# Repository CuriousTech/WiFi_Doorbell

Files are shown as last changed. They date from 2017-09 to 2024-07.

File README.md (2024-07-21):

# WiFi Doorbell Chime

This is a very small doorbell chime based closely on the older version for displaying weather and sending notifications, but eliminates the old mechanical chime. The additional parts are a MOSFET to produce PWM sound, a resistor to eliminate the chime coil and allow parasitic power to supply a smart doorbell or button light, and a WS2812B LED ring, but is still compatible with the old project. The resistor should be about 100 ohms to allow power to the smart doorbell, but I don't know the current rating for them all. A 5W should be sufficient. It's connected to the transformer while the button is pressed, so it needs to handle the current for that time.  
  
Simple operation for detection: The way this circuit operates is when the button is pressed, the optocoupler is disalbled (parrallel to the light in the button), causing the GPIO port (with internal pullup) to go low. The optocoupler vf is 1.2V up to 50mA, but works at 10mA or maybe less. The limiting resistor value will be different for 12V or 24V, so use the proper value. 1K-1K2 is fine for 12V, 2K2-2K4 should be good for 24V, and likely works for 12V as well.  
  
The 3D printed parts have 2 options: A plastic grill or a retainer ring to wrap cloth around and glue. I prefer the latter. The diffuser ring is printed in clear.  
  
esp07doorbell2  
esp07doorbellparts  
esp07doorbellcolor  
  
The OLED version back with 433MHz receiver behind OLED display (cut a bit of plastic) for Reolink video doorbell RF433 output, which works the same as a standard keyfob.  
doorbellreolink  

Previous version below.  

This is an ESP07 based doorbell notifier.  

The 3 terminals connect to the existing 12~24VAC (up to 40V) transformer used to power the bell solenoids and light the neon bulb in the button.  

Btn-DB connects to the wire coming from the button and connects to the bell.<br/>
Btn-TF is the one with a wire cap between the transformer and button.  <br/>
TF-DB is the one coming from the transformer and connects to the bell.<br/>

This uses PushBullet for notifications, which can be enabled from the control page as well as a short list of ring times and last PIR motion trigger time.  It also uses ESPAsyncWebServer for pages, events, WebSockets, Weather Underground, PushBullet and the AP config.  

Wunderground is used for forcast and weather alerts.  If the OLED is truned off, it will only turn on for flashing a bell icon with time, when the PIR motion sensor is triggered (doorbell times will clear after it times out), or a weather alert is active. If the OLED is on, it will show a current condition icon, and scroll the date, time and condition text unless an alert is active.  The doorbell count bar also flashes.  

There's also analog and a few more raw I/O pins broken out for more sensors or controls.  The regulator is 400mA max so it has a bit of room for expansion.  The PIR sensor is supposed to be 5V, but there was a diode and 3V3 regulator that was removed to get it to work with this.  

esp07doorbell  

esp07doorbellInside  

The web page.  
doorbellweb  

doorbellr1

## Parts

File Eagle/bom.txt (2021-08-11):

ESP-07

For existing doorbell display (old)
  I2c OLED (optional)
  PIR sensor (optional)

For new mini doorbell chime
  WS2812B 5050 RGB 24 LED RING 2.6" (65mm)
  36x4.6mm speaker SM360532-3

4mm x 3mm tactile button

The supply is based loosely on the Vreg datasheet suggestion:
VREG           LMR16006YQ5DDCRQ1
D5     SOT-223    NSVR0320MW2T1G
L1     0805 6.8u  IFSC0806AZER6R8M01
C1     10uF+ 25V+ 5mm (25SEPF56M 56uF throughole)
C2     1206 2.2uF
C3     0805 16V 10uF 08056C106KAT2A
C4-C7  0805 16V 0.1uF

OK1    VOS615A-3T (if out of stock, try 1T, 4T, etc.)

R1-R3  0805 10K
R4     0805 2K2
R5,R6  0805 4K7
R9     0805 1K
D1-D4,D6,D7 SOD-123-2 FSV360FP
Q1     SOT-23-3 N-Channel PMV20ENR
3V3    MCP1755T-3302E/OT or MCP1802T-3302I/OT

TH resisistor (simulates doorbell coil for button light or smart doorbell)

X1  Don't use headers or connectors. Too big. Wire direct.

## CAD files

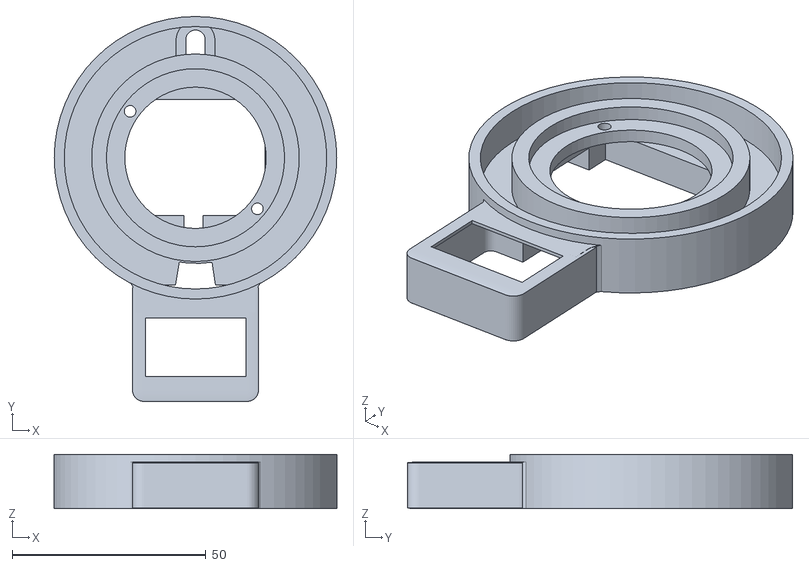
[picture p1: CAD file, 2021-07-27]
3D/DoorbellWithOLED.stl
73.0 x 99.5 x 14.0

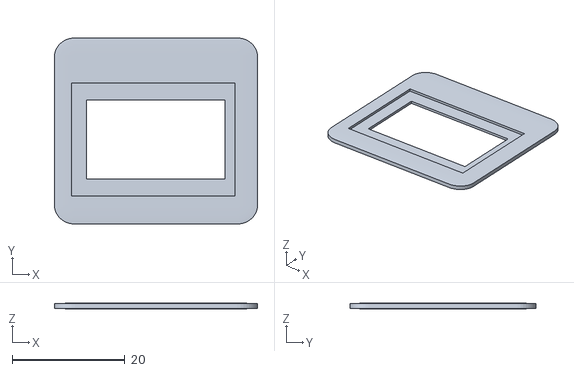
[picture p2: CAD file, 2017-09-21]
OLED Face.stl
36.0 x 33.0 x 1.00

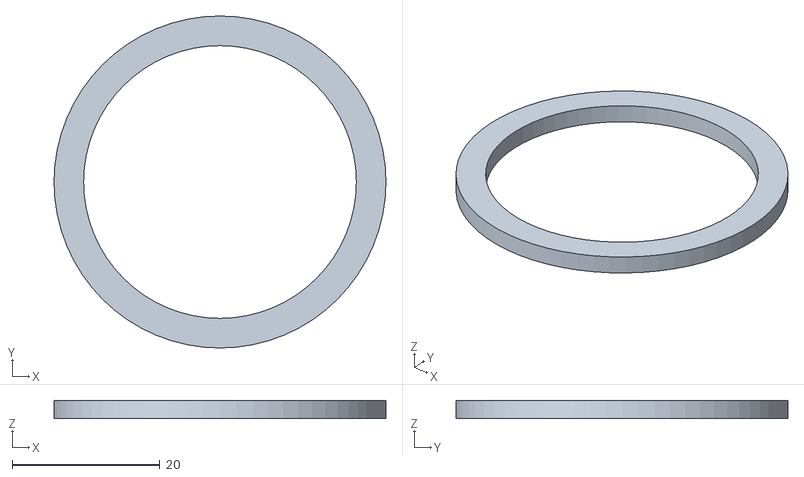
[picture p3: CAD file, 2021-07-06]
3D/Retainer.stl
45.0 x 45.0 x 2.50

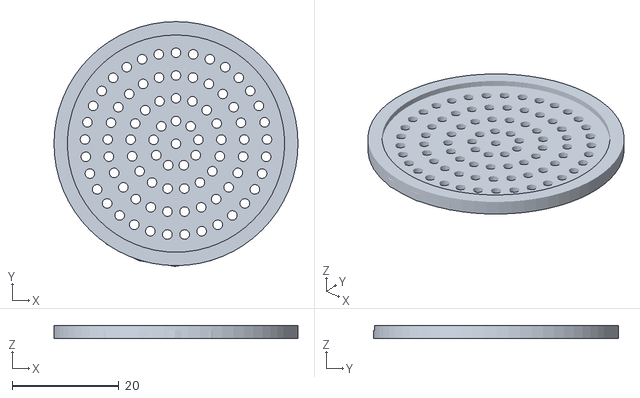
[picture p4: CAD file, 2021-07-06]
3D/Grill.stl
45.8 x 46.0 x 2.50

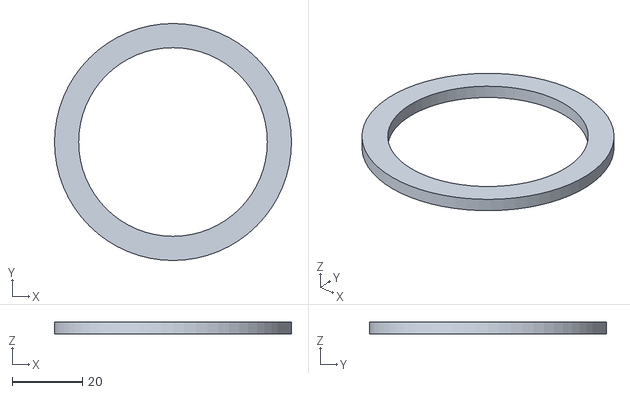
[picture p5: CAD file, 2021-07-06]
3D/DiffuseRing.stl
67.6 x 67.6 x 3.50

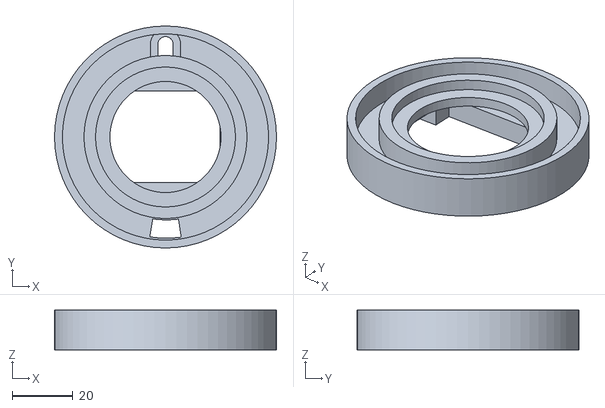
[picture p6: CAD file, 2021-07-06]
3D/Doorbell.stl
73.0 x 73.0 x 13.0

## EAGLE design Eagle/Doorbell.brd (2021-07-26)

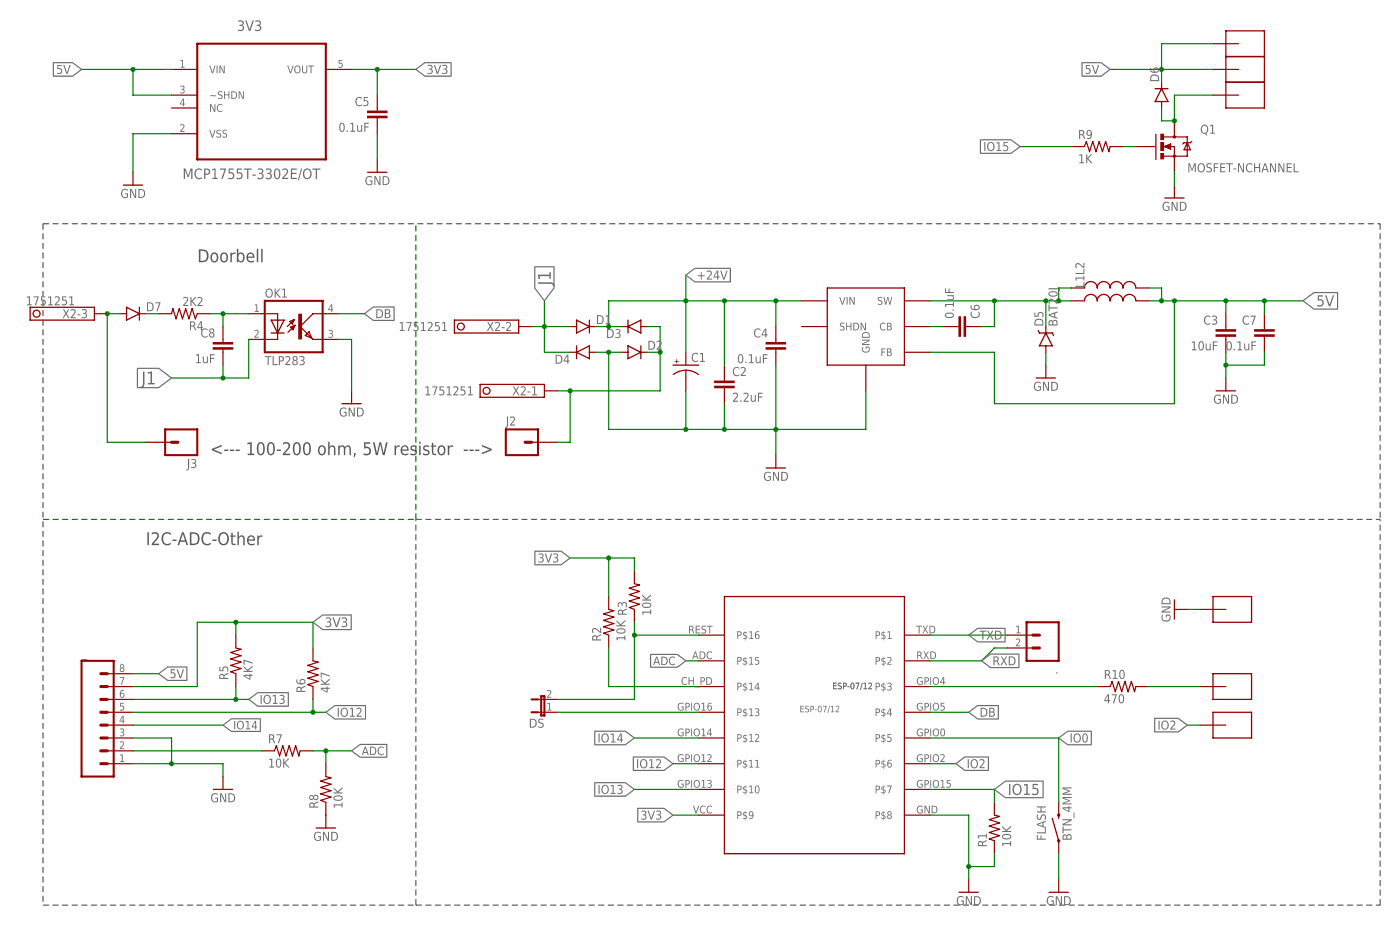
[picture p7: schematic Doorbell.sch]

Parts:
3V3: MCP1755T-3302E/OT; SOT95P270X145-5N
.: M02PTH; 1X02
C1: CAP_POLPTH4; CPOL-RADIAL-1000UF-25V
C2: 2.2uF; 1206
C3: 10uF; 0805-CAP
C4, C5, C6, C7: 0.1uF; 0805-CAP
C8: 1uF; 0805-CAP
D1, D2, D3, D4, D6, D7: DIODESOD123; SOD-123
D5: BAT20J; SOD-323
DS: JUMPER-2SMD-NO; SJ_2S-NO
FLASH: BTN_4MM
J2, J3: M01SMDNS; 1X01NS
L1, L2: INDUCTOR0805; 0805
OK1: TLP283; MINI-FLAT-4
Q1: MOSFET-NCHANNEL; SOT23-3
R1, R2, R3, R7, R8: 10K; 0805
R4: 2K2; 0805
R5, R6: 4K7; 0805
R9: 1K; 0805
R10: 470; 0805
U$1: ESP-07/12
U$2, U$3, U$4, U$5, U$6, U$7: SMD-PAD-SM; SMD-PAD3
VREG: LMR16006YQ5DDCRQ1; SOT-23-6
X2: 1751251
_: M08SILK_FEMALE_PTH; 1X08

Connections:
3V3: 3V3.5 (VOUT), C5.1, R2.2, R3.2, R5.2, R6.2, U$1.VCC, _.7
5V: 3V3.1 (VIN), 3V3.3 (~SHDN), C3.1, C7.1, D6.C, L1.2, L2.2, U$3.P$1, U$7.P$1, VREG.3 (FB), _.8
+24V: C1.+, C2.1, C4.1, D1.C, D3.C, VREG.5 (VIN)
ADC: R7.2, R8.2, U$1.ADC
DB: OK1.4 (COL), U$1.GPIO5
GND: 3V3.2 (VSS), C1.-, C2.2, C3.2, C4.2, C5.2, C7.2, D2.A, D4.A, D5.A, FLASH.1, OK1.3 (EMIT), Q1.2 (S), R1.1, R8.1, U$1.GND, U$4.P$1, VREG.2 (GND), _.1, _.3
ICSPCLK: DS.2, R3.1, U$1.REST
IO0: FLASH.2, U$1.GPIO0
IO2: U$1.GPIO2, U$5.P$1
IO12: R6.1, U$1.GPIO12, _.5
IO13: R5.1, U$1.GPIO13, _.6
IO14: U$1.GPIO14, _.4
IO15: R1.2, R9.1, U$1.GPIO15
IO16: DS.1, U$1.GPIO16
J1: C8.2, D1.A, D4.C, OK1.2 (C), X2.2
unnamed: D6.A, Q1.3 (D), U$6.P$1
unnamed: C8.1, OK1.1 (A), R4.1
unnamed: D2.C, D3.A, J2.1, X2.1
unnamed: R7.1, _.2
unnamed: D7.A, J3.1, X2.3
unnamed: R10.1, U$1.GPIO4
unnamed: C6.1, D5.C, L1.1, L2.1, VREG.6 (SW)
unnamed: Q1.1 (G), R9.2
unnamed: C6.2, VREG.1 (CB)
unnamed: R2.1, U$1.CH_PD
unnamed: R10.2, U$2.P$1
unnamed: D7.C, R4.2
RXD: ..2, U$1.RXD
TXD: ..1, U$1.TXD

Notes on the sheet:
I2C-ADC-Other
Doorbell
<--- 100-200 ohm, 5W resistor --->

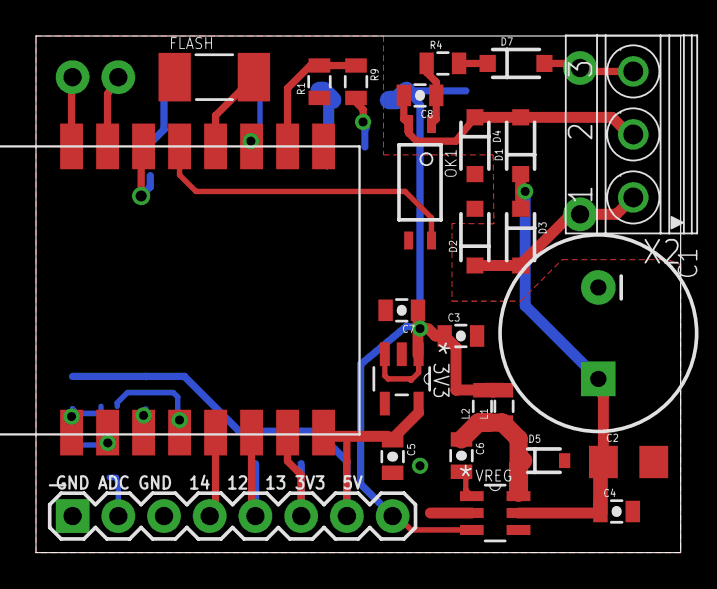
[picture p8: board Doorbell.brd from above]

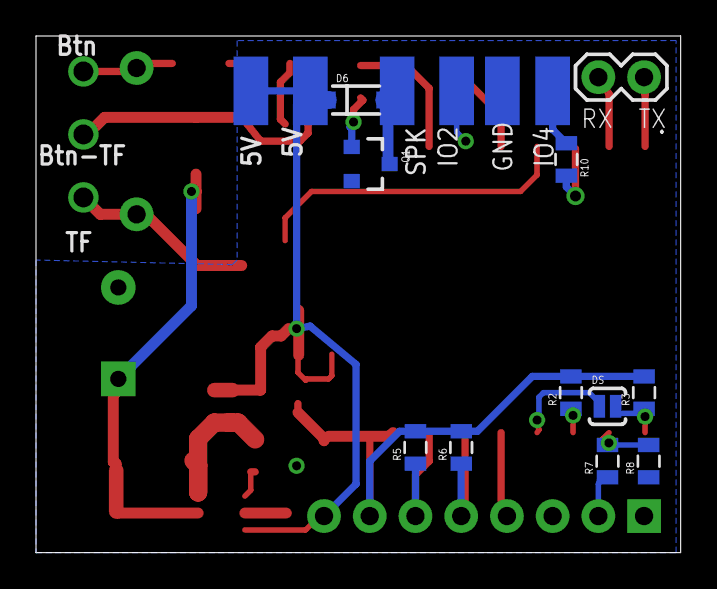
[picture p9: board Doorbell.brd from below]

Board: 2 copper layers, 35.8 x 28.7 mm, 45 parts (17 on the bottom side), 29 nets.

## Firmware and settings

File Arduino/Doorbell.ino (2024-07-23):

/**The MIT License (MIT)

Copyright (c) 2016 by Greg Cunningham, CuriousTech

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
THE SOFTWARE IS PROVIDED "AS IS", WITHOUT WARRANTY OF ANY KIND, EXPRESS OR
IMPLIED, INCLUDING BUT NOT LIMITED TO THE WARRANTIES OF MERCHANTABILITY,
FITNESS FOR A PARTICULAR PURPOSE AND NONINFRINGEMENT. IN NO EVENT SHALL THE
AUTHORS OR COPYRIGHT HOLDERS BE LIABLE FOR ANY CLAIM, DAMAGES OR OTHER
LIABILITY, WHETHER IN AN ACTION OF CONTRACT, TORT OR OTHERWISE, ARISING FROM,
OUT OF OR IN CONNECTION WITH THE SOFTWARE OR THE USE OR OTHER DEALINGS IN THE
SOFTWARE.
*/

// Build with Arduino IDE 1.8.19, esp8266 SDK 3.1.1

#include "config.h"
#include <TimeLib.h> // http://www.pjrc.com/teensy/td_libs_Time.html
#ifdef OLED_ENABLE
#include <Wire.h>
#include "icons.h"
#include <ssd1306_i2c.h>  // https://github.com/CuriousTech/WiFi_Doorbell/tree/master/Libraries/ssd1306_i2c
#endif

#include <EEPROM.h>
#include <ESP8266mDNS.h>
#include <ESPAsyncWebServer.h> // https://github.com/mathieucarbou/ESPAsyncWebServer
#include <UdpTime.h> // https://github.com/CuriousTech/ESP07_WiFiGarageDoor/tree/master/libraries/UdpTime
#ifdef OTA_ENABLE
#include <FS.h>
#include <ArduinoOTA.h>
#endif

#include <JsonClient.h> // https://github.com/CuriousTech/WiFi_Doorbell/tree/master/Libraries/JsonClient
#include "PushBullet.h"
#include "eeMem.h"
#include "pages.h"

#include "jsonstring.h"
#include "Music.h"

#ifdef REOLINK
#include <RCSwitch.h> // from library manager
RCSwitch mySwitch = RCSwitch();
#define RF433     14
#endif

#ifdef LEDRING_ENABLE
#include "LedRing.h"
#endif

const char controlPassword[] = "password"; // device password for modifying any settings
int serverPort = 80; // port to access this device

#define ESP_LED   2  // low turns on ESP blue LED
#define DOORBELL  4 // Note: GPIO4 and GPIO5 are reversed on every pinout on the net
#define NEORING   5
#define SCL       13
#define SDA       12

const char doorbell[] = "Doorbell";

uint32_t lastIP;
int nWrongPass;
UdpTime utime;

Music mus;

#ifdef LEDRING_H
LedRing ring;
#endif

#ifdef OLED_ENABLE
const char *pIcon[4] ={icon11,NULL};
#endif
uint16_t nWeatherID[4];
char szWeather[4][32] = {"NA"}; // short description
char szWeatherLoc[32];
char szWeatherDesc[4][64];   // Severe Thunderstorm Warning, Dense Fog, etc.
float fTemp;
float fTempMin;
float fTempMax;
uint8_t rh;
uint16_t bp;
uint8_t nCloud;
float fWindSpeed;
uint16_t windDeg = 0;
float fWindGust;

#define DB_CNT 16
int doorbellTimeIdx = 0;
uint32_t doorbellTimes[DB_CNT];
bool bAutoClear;
unsigned long dbTime;

#ifdef OLED_ENABLE
SSD1306 display(0x3c, SDA, SCL); // Initialize the oled display for address 0x3c, sda=12, sdc=13
bool bStartOLED;
int displayOnTimer;             // temporary OLED turn-on
//void Scroller(String s);
void convertIcon(uint8_t ni, bool bNight);
#endif

AsyncWebServer server( serverPort );
AsyncWebSocket ws("/ws"); // access at ws://[esp ip]/ws

PushBullet pb;

eeMem ee;

bool bConfigDone = false;
bool bStarted = false;
uint32_t connectTimer;

void sendState(void);
// WebSocket
void jsonCallback(int16_t iName, int iValue, char *psValue);
JsonClient jsonParse(jsonCallback);
JsonClient jsNotif(jsonCallback); // notifier (push to another device)

// OpenWeatherMap api
void owCallback(int16_t iName, int iValue, char *psValue);
JsonClient owClient(owCallback, 2200);
void innerCallback(int16_t iName, int iValue, char *psValue);
JsonClient innerParse(innerCallback, 1200);
void owCall(void);

String dataJson() // timed/instant pushed data
{
  jsonString js("state");
  js.Var("t", (uint32_t)( now() - ((ee.tz + utime.getDST()) * 3600) ) );
  js.Var("tz", ee.tz);
  js.Var("weather", szWeather[0] );
  js.Var("bellCount", doorbellTimeIdx);
  js.Var("o", ee.bEnableOLED );
  js.Var("pbdb", ee.bEnablePB[0] );
  js.Var("pbm", ee.bEnablePB[1] );
  js.Var("loc",  ee.location );
  js.Var("alert", szWeatherDesc[0] );
  js.Var("temp", String(fTemp, 1) );
  js.Var("rh", rh);
  js.Var("wind", String(fWindSpeed, 1) + " " + windDeg + "deg" );
  js.Var("m", ee.melody);
  js.Array("db", doorbellTimes, DB_CNT);
  js.Var("ef", ee.effect);
  js.Var("br", ring.m_brightness);
  return js.Close();

// for(int i = 0; szWeather[i][0] && i < 4; i++)
//  {
//    if(i) s += ",";
//    s += szWeather[i];
//  }
}

void parseParams(AsyncWebServerRequest *request)
{
  char password[64] = "";
  int val;
  bool bRemote = false;
  bool ipSet = false;

  if(request->params() == 0)
    return;

  // get password first
  for ( uint8_t i = 0; i < request->params(); i++ ) {
    const AsyncWebParameter* p = request->getParam(i);

    String s = request->urlDecode(p->value());

    switch( p->name().charAt(0)  )
    {
      case 'k': // key
        s.toCharArray(password, sizeof(password));
        break;
    }
  }

  uint32_t ip = request->client()->remoteIP();

  if(strcmp(controlPassword, password) || nWrongPass)
  {
    if(nWrongPass == 0) // it takes at least 10 seconds to recognize a wrong password
      nWrongPass = 10;
    else if((nWrongPass & 0xFFFFF000) == 0 ) // time doubles for every high speed wrong password attempt.  Max 1 hour
      nWrongPass <<= 1;
    if(ip != lastIP)  // if different IP drop it down
       nWrongPass = 10;
    jsonString js("hack");
    js.Var("ip", request->client()->remoteIP().toString() );
    js.Var("pass", password);
    ws.textAll(js.Close());
    lastIP = ip;
    return;
  }

  lastIP = ip;

  const char Names[][10]={
    "OLED", // 0
    "reset",
    "loc",
    "owkey",
    "pbtoken",
    "notifip",
    "notifpath",
    "notifport",
    "play", // 10
    "light",
    "lighttime",
  };

  for ( uint8_t i = 0; i < request->params(); i++ ) {
    const AsyncWebParameter* p = request->getParam(i);
    String s = request->urlDecode(p->value());
    bool bValue = (s == "true" || s == "1") ? true:false;
//    Serial.println( i + " " + server.argName ( i ) + ": " + s);

    uint8_t idx;
    for(idx = 0; Names[idx][0]; idx++)
      if( p->name().equals(Names[idx]) )
        break;

    switch( idx )
    {
      case 0: // OLED
        ee.bEnableOLED = bValue;
        if(bValue) bStartOLED = true;
        break;
      case 1: // reset
        doorbellTimeIdx = 0;
#ifdef LEDRING_H
        ring.setIndicatorCount(doorbellTimeIdx);
#endif
        break;
      case 2: // location
        s.toCharArray(ee.location, sizeof(ee.location));
        break;
      case 3: // openweathermap key
        s.toCharArray(ee.owKey, sizeof(ee.owKey));
        break;
      case 4: // pushbullet token
        s.toCharArray(ee.pbToken, sizeof(ee.pbToken));
        break;
      case 5: // notifip   /s?key=password&notifip="192.168.0.102"&notifpath="/test"&notifport=82
         strncpy(ee.szNotifIP, s.c_str(), sizeof(ee.szNotifIP));
         break;
      case 6: // path
         strncpy(ee.szNotifPath, s.c_str(), sizeof(ee.szNotifPath));
         break;
      case 7: // notifport
         ee.NotifPort = atoi(s.c_str());
         break;
      case 8: // play
         mus.play(s.toInt());
         break;
      case 9: // light
#ifdef LEDRING_H
         ring.light(s.toInt());
#endif
        break;
      case 10: // lighttime
#ifdef LEDRING_H
         ring.lightTimer(s.toInt());
#endif
         break;
    }
  }
}

// Current time in hh:mm:ss AM/PM
String timeFmt()
{
  String r = "";
  if(hourFormat12() < 10) r = " ";
  r += hourFormat12();
  r += ":";
  if(minute() < 10) r += "0";
  r += minute();
  r += ":";
  if(second() < 10) r += "0";
  r += second();
  r += " ";
  r += isPM() ? "PM":"AM";
  return r;
}

String timeToTxt(uint32_t &t)  // GMT to string "Sun 12:00:00 AM"
{
  tmElements_t tm;
  breakTime(t + (3600 * (ee.tz + utime.getDST())), tm);
 
  String s = dayShortStr(tm.Wday);
  s += " ";
  int h = tm.Hour;
  if(h == 0) h = 12;
  else if(h > 12) h -= 12;
  s += h;
  s += ":";
  if(tm.Minute < 10)  s += "0";
  s += tm.Minute;
  s += ":";
  if(tm.Second < 10)  s += "0";
  s += tm.Second;
  s += " ";
  s += tm.Hour > 11 ? "PM" : "AM";  
  return s;
}

void reportReq(AsyncWebServerRequest *request) // report full request to PC
{
  jsonString js("remote");
  js.Var("remote", request->client()->remoteIP().toString() );
  js.Var("method", request->methodToString());
  String s = request->host();
  if(s == "")
  {
    s = request->client()->localIP().toString();
  }
  js.Var("host", s );
  js.Var("url", request->url() );

  if(request->contentLength()){
    js.Var("contentType", request->contentType().c_str() );
    js.Var("contentLen", request->contentLength() );
  }

  js.ArrayHdrs("header", request);
  js.ArrayPrms("params", request);

  ws.textAll(js.Close());
}

void handleS(AsyncWebServerRequest *request)
{
  parseParams(request);

  jsonString js;
  String s = WiFi.localIP().toString() + ":";
  s += serverPort;
  js.Var("ip", s);
  request->send( 200, "text/json", js.Close() );
  reportReq(request);
}

// JSON format for initial or full data read
void handleJson(AsyncWebServerRequest *request)
{
  jsonString js;

  js.Var("weather", szWeather[0] );
  js.Var("location", ee.location);
  js.Var("bellCount", doorbellTimeIdx);
  js.Var("display", ee.bEnableOLED );
  js.Var("temp", String(fTemp, 1) );
  js.Var("rh", rh);
  js.Var("time", (uint32_t)( now() - ((ee.tz + utime.getDST()) * 3600) ) );
  js.Var("opto", digitalRead(DOORBELL) );
  js.Array("t", doorbellTimes, DB_CNT);
  request->send( 200, "text/json", js.Close() );
}

const char *jsonListCmd[] = { // WebSocket command list
  "key",
  "reset",
  "pbdb", // pushbullet doorbell option
  "pbm", // pushbullet motion
  "mot", // motion
  "oled",
  "loc", // location
  "TZ",
  "ef", // LED effect
  "play",
  "cnt", // LED count
  "m", // melody for doorbell
  "br", // brightness
  "light",
  "lighttime",
  NULL
};

bool bKeyGood;

void jsonCallback(int16_t iName, int iValue, char *psValue)
{
  if(iName && !bKeyGood)
    return;
  switch(iName)
  {
    case 0: // key
      if(!strcmp(psValue, controlPassword)) // first item must be key
        bKeyGood = true;
      break;
    case 1: // reset
      if(doorbellTimeIdx)
      {
        doorbellTimeIdx = 0;
        memset(doorbellTimes, 0, sizeof(doorbellTimes));
        sendState();
#ifdef LEDRING_H
        ring.setIndicatorCount(doorbellTimeIdx);
#endif
      }
      break;
    case 2: // pbdb
      ee.bEnablePB[0] = iValue;
      break;
    case 3: // pbm
      ee.bEnablePB[1] = iValue;
      break;
    case 4: // motion
      ee.bMotion =iValue;
      break;
    case 5: // OLED
      ee.bEnableOLED = iValue ? true:false;
      if(iValue) bStartOLED = true;
      break;
    case 6: // loc
      strncpy(ee.location, psValue, sizeof(ee.location));
      break;
    case 7: // TZ
      ee.tz = iValue;
      utime.start();
      break;
    case 8: // effect
#ifdef LEDRING_H
      ring.setEffect(iValue);
      ee.effect = iValue;
#endif
      break;
    case 9: // music
      ee.melody = iValue;
      mus.play(iValue);
      break;
    case 10: // indicator count
#ifdef LEDRING_H
      ring.setIndicatorCount(iValue);
#endif
      break;
    case 11: // melody
      ee.melody = iValue;
      break;
    case 12: // brightnes
#ifdef LEDRING_H
      ring.setBrightness(iValue);
#endif
      break;
    case 13: // light
#ifdef LEDRING_H
      ring.light(iValue);
#endif
      break;
    case 14: // lighttime
#ifdef LEDRING_H
      ring.lightTimer(iValue);
#endif
      break;
  }
}

void onWsEvent(AsyncWebSocket * server, AsyncWebSocketClient * client, AwsEventType type, void * arg, uint8_t *data, size_t len)
{  //Handle WebSocket event
  static bool bReset = true;
  String s;

  switch(type)
  {
    case WS_EVT_CONNECT:      //client connected
      if(bReset)
      {
        client->text( "{\"cmd\":\"alert\",\"text\":\"Restarted\"}" );
        bReset = false;
      }
      client->text(dataJson());
      client->ping();
      break;
    case WS_EVT_DISCONNECT:    //client disconnected
      break;
    case WS_EVT_ERROR:    //error was received from the other end
      break;
    case WS_EVT_PONG:    //pong message was received (in response to a ping request maybe)
      break;
    case WS_EVT_DATA:  //data packet
      AwsFrameInfo * info = (AwsFrameInfo*)arg;
      if(info->final && info->index == 0 && info->len == len){
        //the whole message is in a single frame and we got all of it's data
        if(info->opcode == WS_TEXT){
          data[len] = 0;

          bKeyGood = false; // for callback (all commands need a key)
          jsonParse.process((char*)data);
        }
      }
      break;
  }
}

static int ssCnt = 30;
void sendState()
{
  ws.textAll(dataJson());
  ssCnt = 59 - second();
  if(ssCnt < 20) ssCnt = 59;
}

volatile bool bDoorBellTriggered;
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
void loop()
{
  static uint8_t sec_save, min_save, hour_save;

  MDNS.update();
#ifdef OTA_ENABLE
  ArduinoOTA.handle();
#endif

  if(WiFi.status() == WL_CONNECTED)
  {
    if(utime.check(ee.tz))
      ring.setEffect(ee.effect);
  }

  if(bDoorBellTriggered)
  {
    bDoorBellTriggered = false;
    doorBell();
  }

#ifdef REOLINK
  if(mySwitch.available())
  {
    uint32_t code = mySwitch.getReceivedValue();
    if(ee.reolinkCode && code == ee.reolinkCode)
      doorBell();
    else
    {
      jsonString js("alert");
      String s = "RF code ";
      s += code;

      if( ee.reolinkCode == 0)
      {
        ee.reolinkCode = code;
        s += " set";
      }
      js.Var("text", s);
      ws.textAll(js.Close());
    }
  }
#endif

  if(sec_save != second()) // only do stuff once per second (loop is maybe 20-30 Hz)
  {
    sec_save = second();

    if(!bConfigDone)
    {
      if( WiFi.smartConfigDone())
      {
        WiFi.mode(WIFI_STA);
        Serial.println("SmartConfig set");
        bConfigDone = true;
        connectTimer = now();
      }
    }
    if(bConfigDone)
    {
      if(WiFi.status() == WL_CONNECTED)
      {
        if(!bStarted)
        {
          Serial.println("WiFi Connected");
          WiFi.mode(WIFI_STA);
          MDNS.begin( doorbell );
          bStarted = true;
          MDNS.addService("iot", "tcp", serverPort);
          WiFi.SSID().toCharArray(ee.szSSID, sizeof(ee.szSSID)); // Get the SSID from SmartConfig or last used
          WiFi.psk().toCharArray(ee.szSSIDPassword, sizeof(ee.szSSIDPassword) );

          utime.start();
        }
      }
      else if(now() - connectTimer > 10) // failed to connect for some reason
      {
        Serial.println("Connect failed. Starting SmartConfig");
        connectTimer = now();
//        ee.szSSID[0] = 0;
        WiFi.mode(WIFI_AP_STA);
        WiFi.beginSmartConfig();
        bConfigDone = false;
        bStarted = false;
      }
    }

    if(--ssCnt == 0) // heartbeat I guess
    {
      sendState();
    }

    if(min_save != minute())
    {
      min_save = minute();

      if (hour_save != hour())  // update our time daily (at 2AM for DST)
      {
        if( (hour_save = hour()) == 2 && WiFi.status() == WL_CONNECTED)
          utime.start();
        ee.update(); // update EEPROM if needed while we're at it (give user time to make many adjustments)
      }
      if (min_save == 0) // hourly stuff
      {
        uint32_t t = now() - (3600 * ee.tz);
        if(doorbellTimeIdx && doorbellTimes[0] < t - (3600 * 24 *7) ) // 1 week old
        {
          doorbellTimeIdx--;
          if(doorbellTimeIdx)
            memcpy(doorbellTimes, &doorbellTimes[doorbellTimeIdx], sizeof(uint32_t) * (DB_CNT-doorbellTimeIdx) );
#ifdef LEDRING_H
          ring.setIndicatorCount(doorbellTimeIdx);
#endif
        }
      }
      static uint8_t owCnt = 1;
      if(--owCnt == 0)
      {
        owCnt = 10; // every 10 mins
        owCall();
      }
    }

    if(displayOnTimer) // if alerts or messages, turn the display on
      if(--displayOnTimer == 0)
      {
        if(bAutoClear) // motion activated doorbell rings display
        {
          if(ee.bMotion) doorbellTimeIdx = 0;
          bAutoClear = false;
#ifdef LEDRING_H
          ring.setIndicatorCount(doorbellTimeIdx);
#endif
        }
      }

    if(nWrongPass)
      nWrongPass--;

    draw();
  }

#ifdef LEDRING_H
  ring.service();
#endif

  mus.service();

  if(WiFi.status() != WL_CONNECTED)
    return;

#ifdef OLED_ENABLE
#ifdef LEDRING_H
  display.updateChunk();
#else
  display.display();
#endif // LEDRING_H
#endif // OLED
}

void draw()
{
#ifdef OLED_ENABLE
  if(WiFi.status() != WL_CONNECTED)
    return;

  static int16_t ind;
  static bool blnk = false;
  static long last_blnk;
  static long last_min;
  static int16_t iconX = 0;
  static int16_t infoX = 64;
  String s;

  if(minute() != last_min) // alternate the display to prevent burn
  {
    last_min = minute();
    if(iconX){ iconX = 0;   infoX = 64; }
    else     { infoX = 0;   iconX = 64; }
  }

  // draw the screen here
  display.clear();

  if( (millis() - last_blnk) > 400) // 400ms toggle for blinky things
  {
    last_blnk = millis();
    blnk = !blnk;
  }
  if(bStartOLED)
  {
    bStartOLED = false;
    display.init();
  }
  if( (ee.bEnableOLED || displayOnTimer) && (bAutoClear == false)) // skip for motion enabled display
  {
    static uint8_t nIcon;
    static uint8_t nSec;
    if(nSec != second())
    {
      nSec = second();
      nIcon = (nIcon + 1) & 3; // alternate multiple icons
      if(pIcon[nIcon] == NULL)
        nIcon = 0;
    }

    display.drawXbm(iconX+10, 20, 44, 42, pIcon[nIcon]);

    static uint8_t d;
    switch(d>>3)
    {
      default:
        d = 0;
      case 0:
        s = timeFmt();
        break;
      case 1:
        s = "  ";
        s += dayShortStr(weekday());
        s += "  ";
        s += String(day());
        s += "  ";
        s += monthShortStr(month());
        break;
      case 2:
        s = szWeather[0];
        break;
    }
    d++;

    display.drawPropString(0, 0, s ); // time
    display.drawPropString(infoX, 23, String(fTemp, 1) + "]" );
    display.drawString(infoX + 20, 43, String(rh) + "%");
    if(blnk && doorbellTimeIdx) // blink small gauge if doorbell logged
    { // up to 64 pixels (128x64)
      display.fillRect(infoX, 61, doorbellTimeIdx << 2, 3);
    }
  }
  else if(doorbellTimeIdx) // blink a bell if doorbell logged and display is off
  {
    display.drawPropString(0, 0, timeToTxt(doorbellTimes[0]) ); // the first time
    if(blnk) display.drawXbm(iconX+10, 20, 44, 42, bell);
    display.drawPropString(infoX + 5, 23, String(doorbellTimeIdx) ); // count
  }
#endif
}

///////////////
// things we want from conditions request
const char *jsonListOw[] = {
  "weather",   // 0
  "main",      // 
  "wind",      //
  "rain",
  "snow",
  "clouds",    //
  "dt",        //
  "sys",       //
  "id",        //
  "name",      //
  "cod",      // 10
  NULL
};

const char *jsonListWeather[] = {
  "id",      // 0
  "main",
  "description",
  "icon",
  NULL
};

const char *jsonListMain[] = {
  "temp",      // 0
  "pressure",
  "humidity",
  "temp_min",
  "temp_max",
  NULL
};
const char *jsonListWind[] = {
  "speed",      // 0
  "deg",
  "gust",
  NULL
};
const char *jsonListRain[] = {
  "1h",      // 0
  "3h",
  NULL
};
const char *jsonListSnow[] = {
  "1h",      // 0
  "3h",
  NULL
};
const char *jsonListClouds[] = {
  "all",      // 0
  NULL
};

uint8_t nWeatherIdx;
uint8_t nParseIdx;
void owCallback(int16_t iName, int iValue, char *psValue)
{
  switch(iName)
  {
    case 0: // weather [{},{},{}] array
      nWeatherIdx = 0;
#ifdef OLED_EBALE
      memset(pIcon, 0, sizeof(pIcon));
#endif
      memset(nWeatherID, 0, sizeof(nWeatherID));
      memset(szWeather, 0, sizeof(szWeather));
      memset(szWeatherDesc, 0, sizeof(szWeatherDesc));
      innerParse.setList(jsonListWeather);
      nParseIdx = 0;
      innerParse.process(psValue);
      break;
    case 1: // main
//      ws.textAll(String("{\"cmd\":\"print\",\"main\":\"") + psValue + "\"");
      innerParse.setList(jsonListMain);
      nParseIdx = 1;
      innerParse.process(psValue);
      break;
    case 2: // wind
      innerParse.setList(jsonListWind);
      nParseIdx = 2;
      innerParse.process(psValue);
      break;
    case 3: // rain
      innerParse.setList(jsonListRain);
      nParseIdx = 3;
      innerParse.process(psValue);
      break;
    case 4: // snow
      innerParse.setList(jsonListSnow);
      nParseIdx = 4;
      innerParse.process(psValue);
      break;
    case 5: // clouds
      innerParse.setList(jsonListClouds);
      nParseIdx = 5;
      innerParse.process(psValue);
      break;
    case 6: // dt
//    ws.textAll(String("{\"cmd\":\"print\",\"dt\":") + psValue + "}");
      break;
    case 7: // sys {"type":1,"id":1128,"message":0.0033,"country":"US","sunrise":1542284504,"sunset":1542320651}
//      ws.textAll(String("{\"cmd\":\"print\",\"sys\":\"") + psValue + "\"");
      break;
    case 8: // id
      break;
    case 9: // name
      strncpy(szWeatherLoc, psValue, strlen(szWeatherLoc));
      break;
    case 10: // cod
      if(iValue != 200)
        ws.textAll(String("{\"cmd\":\"print\",\"errcode\":\"") + iValue + "\"");
      break;
  }
}

// Call OpenWeathermap API
void owCall()
{
  if(WiFi.status() != WL_CONNECTED)
    return;
  String path = "/data/2.5/weather?id=";

  path += ee.location;
  path += "&APPID=";
  path += ee.owKey;
  path += "&units=imperial";

  owClient.begin("api.openweathermap.org", path.c_str(), 80, false);
  owClient.setList(jsonListOw);
}
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

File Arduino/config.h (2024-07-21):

// Configuration options

#define OTA_ENABLE    // Uncomment to enable Arduino IDE Over The Air update code
#define OLED_ENABLE   // Uncomment for OLED
#define LEDRING_ENABLE // Uncomment for LED ring
#define REOLINK // Uncomment for Reolink RF receiver (433MHz 3.3-5.0V)

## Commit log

2016-06-21 More secure, alerts fixed, etc.
    [Doorbell.ino]
2016-06-23 r1 - switching supply
    [Doorbell.sch]
2016-07-22 fixed buffer overrun on alert message cnv
    [Doorbell.ino]
2016-09-23 Switched to ESPAsyncWebServer
2017-03-13 weather/alert logic fix, OTA
    [Doorbell.ino]
2017-07-06 Fix for printfAll
2017-09-21 3D printed faceplate
    [OLED Face.stl]
2018-04-21 Alert clear fix, extra push to URL
    [Doorbell.ino]
2018-05-01 Removed printf
2021-07-22 Switched to FastLED
2021-07-22 Switched to FastLED for stability
    [LedRing.cpp]
2021-07-22 analogWriteFreq(0) crashes. Workaround added
    [music.cpp]
2021-07-26 Added the inline diode
    [Doorbell.brd, Doorbell.sch]
2021-07-27 Larger space for Geekcreit 0.96 OLED module
    [DoorbellWithOLED.stl]
2021-09-20 OLED display issues when connecting
    [Doorbell.ino]
2021-10-03 Eliminates powerup ring
2023-01-26 Delete WiFiManager.cpp
    Switched to SmartConnect
2023-01-26 Update Doorbell.ino
    Switched to EspTouch/SmartConnect

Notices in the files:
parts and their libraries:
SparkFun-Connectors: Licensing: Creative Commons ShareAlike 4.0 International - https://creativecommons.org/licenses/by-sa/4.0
